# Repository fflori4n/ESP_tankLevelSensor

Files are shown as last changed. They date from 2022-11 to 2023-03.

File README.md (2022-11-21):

# ESP_tankLevelSensor

ESP32 measuring water level in a reservoar, using an external LM555 oscillator and a capacitive probe. 

Measurements are displayed on MAX7219 driven 7seg. displays and the uController hosts it's on webserver that displays the tank status and stats. Board has a linear regulator to drop the 12V DC from the truck's battery to 5V for the ESP and the sensor, two relays that can switch 12V DC external loads ( meant for signal lights ), and can drive WS2812B LED strip to indicate level in the tank.

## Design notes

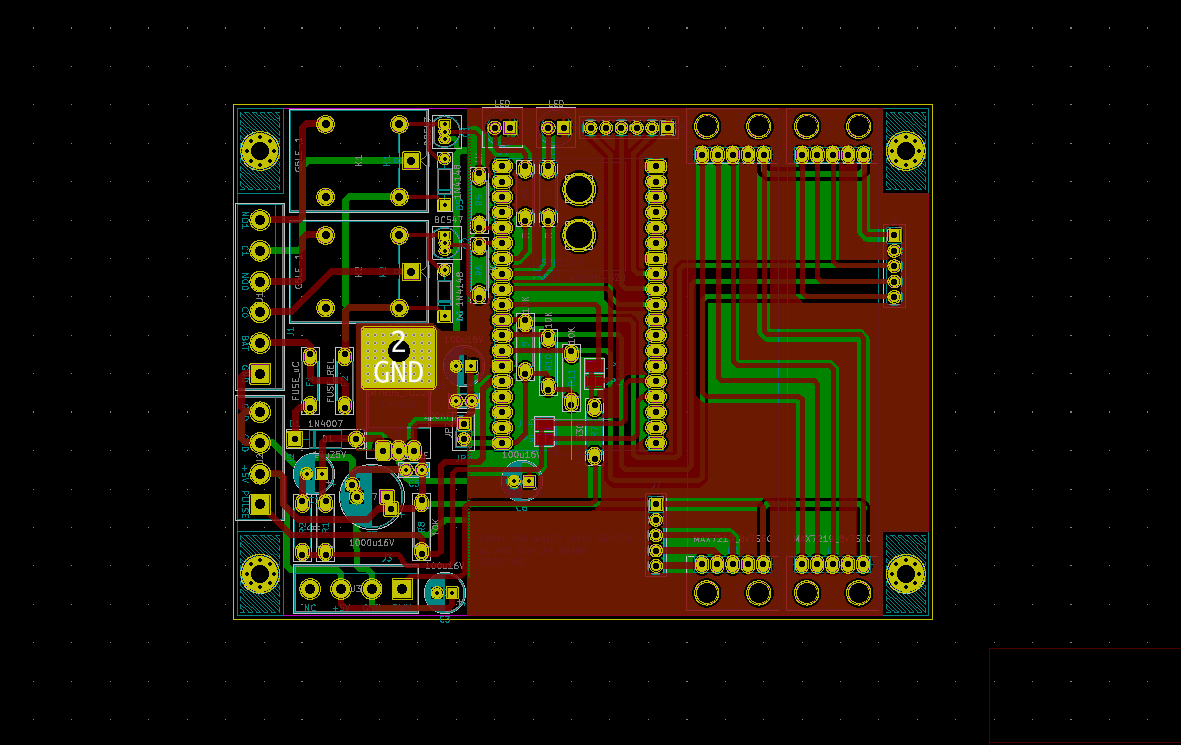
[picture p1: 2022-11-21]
doucmentation/Screenshot_pcb.png

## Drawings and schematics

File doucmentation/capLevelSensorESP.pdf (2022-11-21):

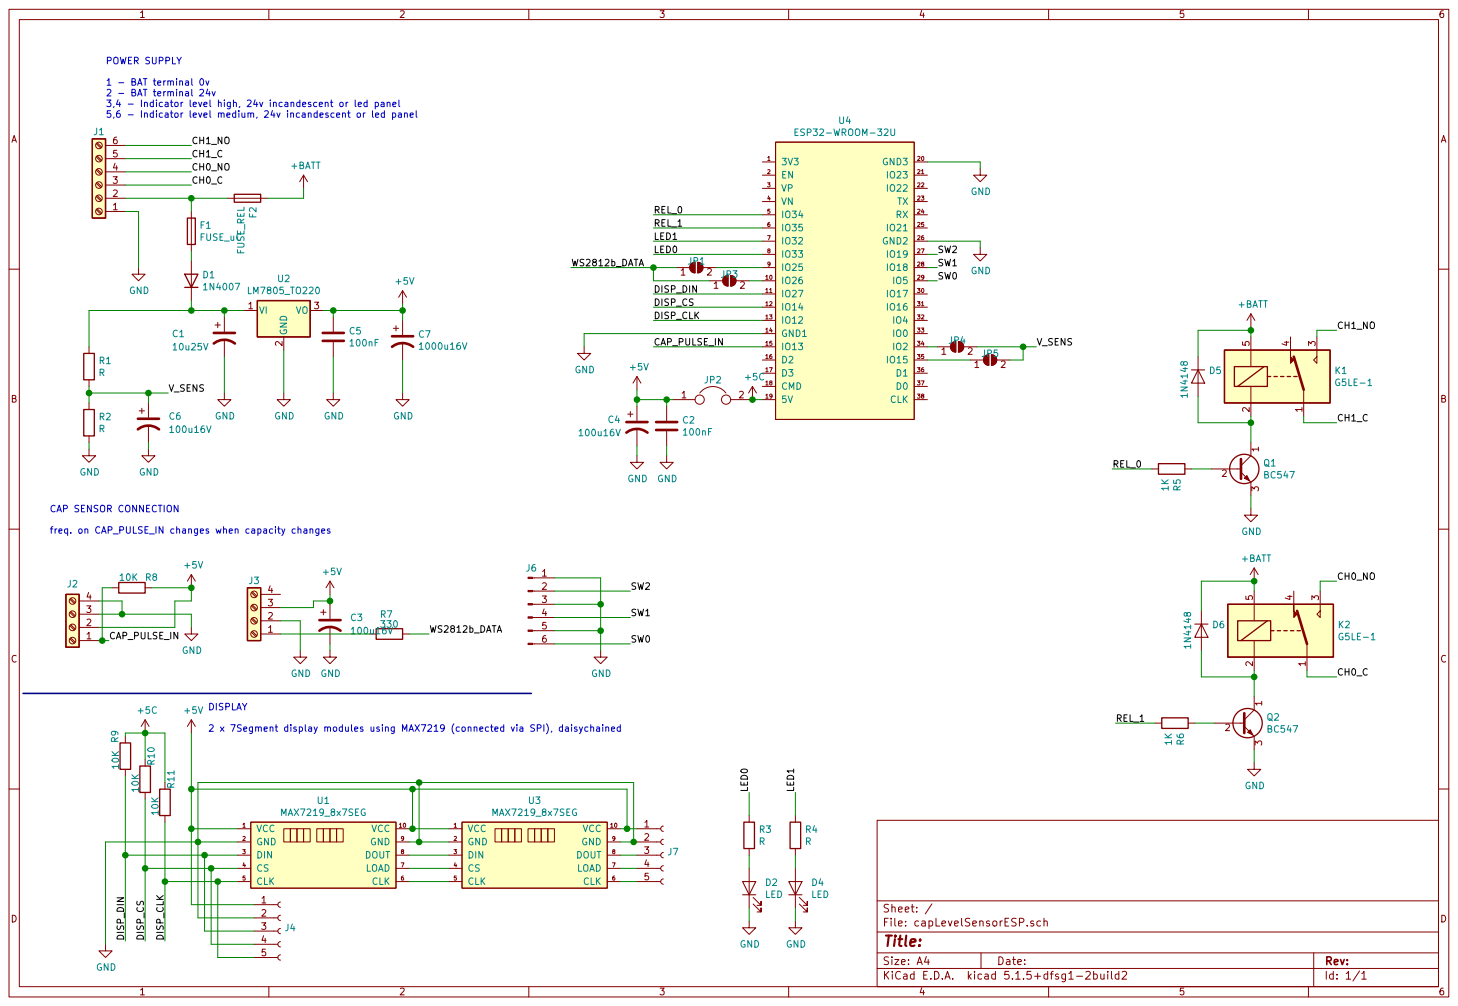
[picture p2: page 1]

1 - BAT terminal 0v 2 - BAT terminal 24v 3,4 - Indicator level high, 24v incandescent or led panel

File: capLevelSensorESP.sch Sheet: / F2 FUSE_REL

freq. on CAP_PULSE_IN changes when capacity changes DISPLAY

2 x 7Segment display modules using MAX7219 (connected via SPI), daisychained

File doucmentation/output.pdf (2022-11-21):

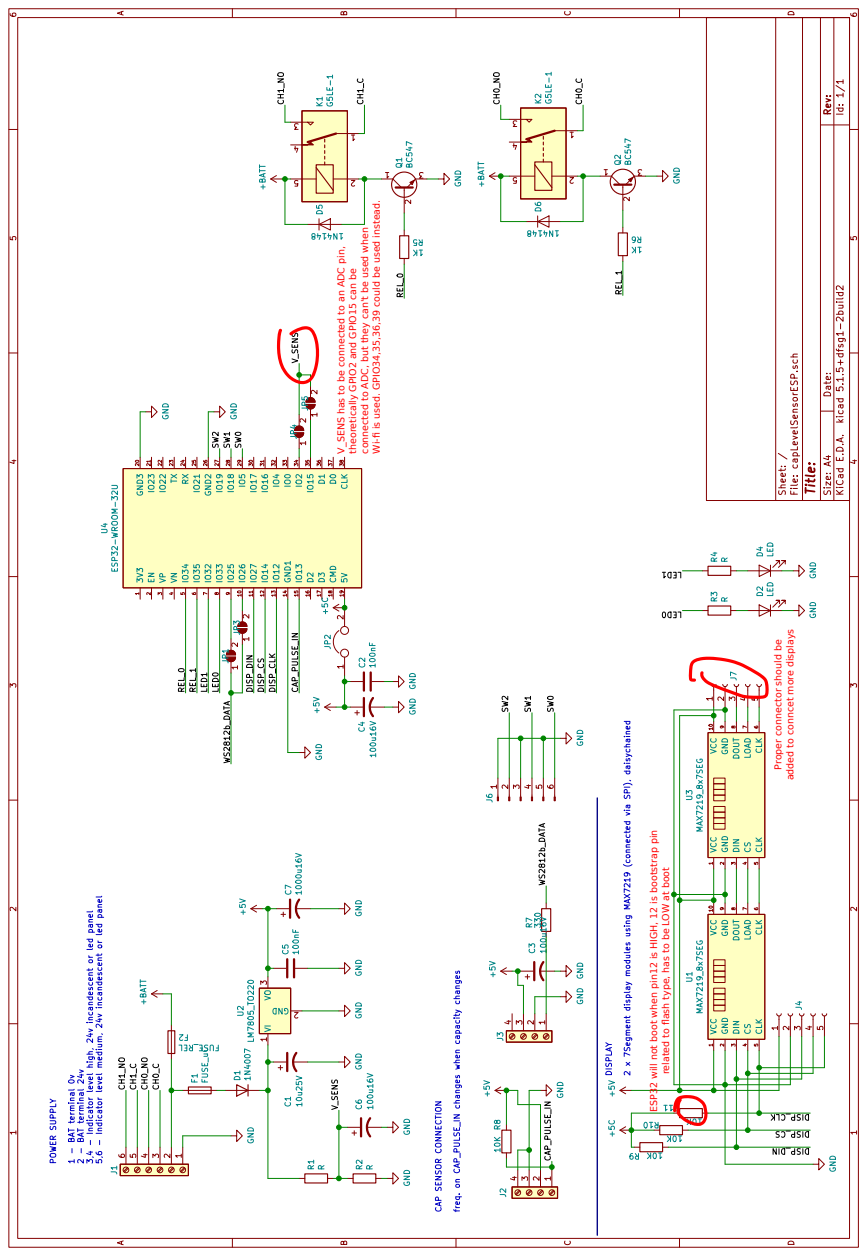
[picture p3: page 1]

Wi-fi is used. GPIO34,35,36,39 could be used instead.

connected to ADC, but they can't be used when

V_SENS has to be connected to an ADC pin,

theoretically GPIO2 and GPIO15 can be

added to conncet more displays

Proper connector should be

ESP32 will not boot when pin12 is HIGH, 12 is bootstrap pin

related to flash type, has to be LOW at boot

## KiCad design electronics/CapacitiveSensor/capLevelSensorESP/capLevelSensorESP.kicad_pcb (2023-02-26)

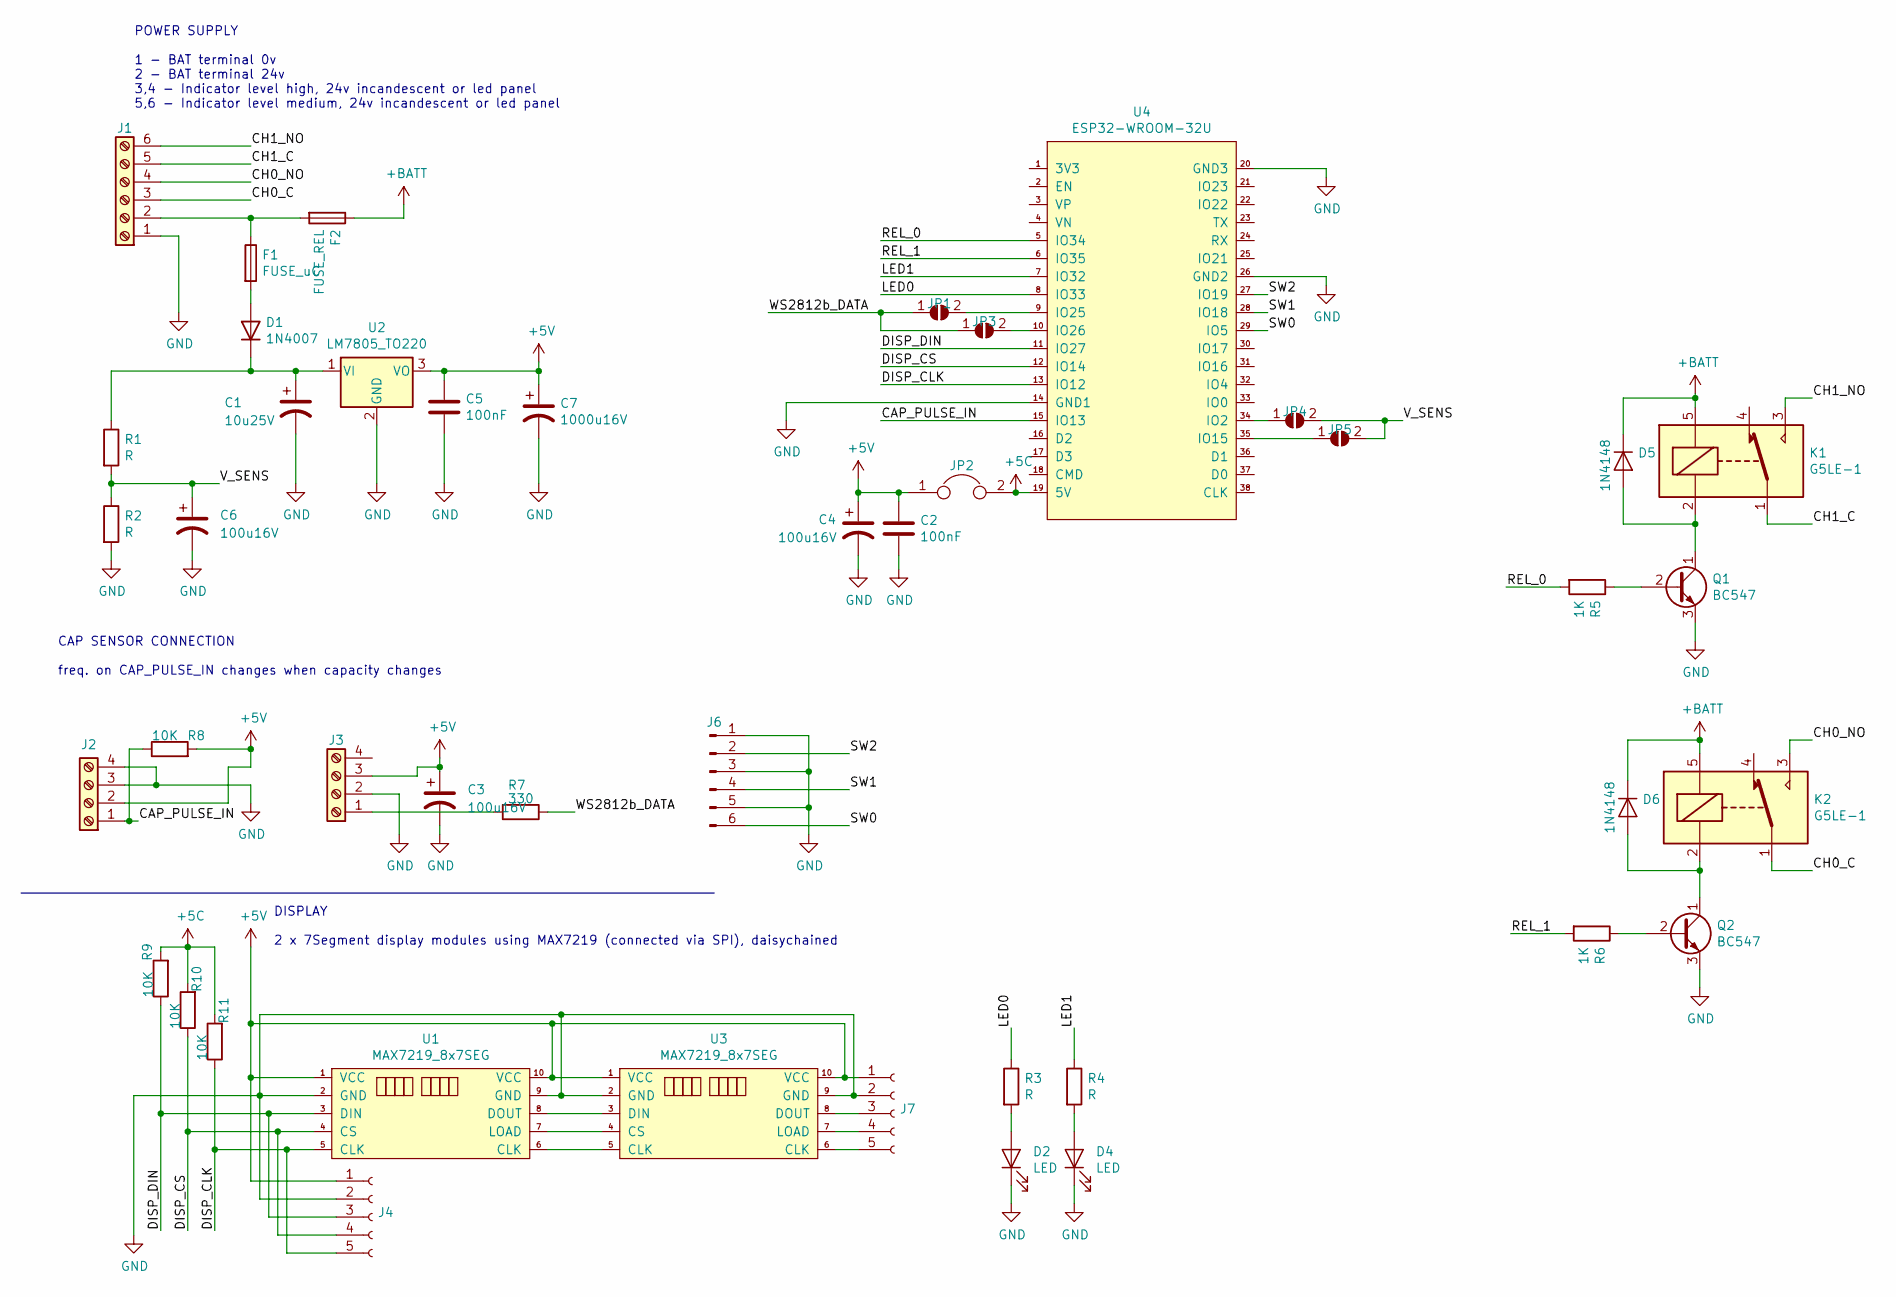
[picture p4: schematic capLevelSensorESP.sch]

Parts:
C1: 10u25V; CP_Radial_D6.3mm_P2.50mm
C2, C5: 100nF; Capker_L4.6mm_W2.0mm_P2.50mm
C3, C4, C6: 100u16V; CP_Radial_D6.3mm_P2.50mm
C7: 1000u16V; CP_Radial_D10.0mm_P5.00mm_P7.50mm
D1: 1N4007; D_DO-41_SOD81_P10.16mm_Horizontal
D2, D4: LED; LED_D5.0mm_FlatTop
D5, D6: 1N4148; D_DO-35_SOD27_P7.62mm_Horizontal
F1: FUSE_uC; resistor0.25,9mm
F2: FUSE_REL; resistor0.25,9mm
J1: TerminalBlock_bornier-6_P5.08mm
J2, J3: TerminalBlock_bornier-4_P5.08mm
J4, J7: PinHeader_1x05_P2.54mm_Vertical
J6: PinHeader_1x06_P2.54mm_Vertical
JP1, JP3, JP4, JP5: SolderJumper-2_P1.3mm_Open_Pad1.0x1.5mm
JP2: PinHeader_1x02_P2.54mm_Vertical
K1, K2: G5LE-1; Relay_SPDT_Omron-G5LE-1
Q1, Q2: BC547; TO-92_Inline
R1, R2, R3, R4: R; resistor0.25,9mm
R5, R6: 1K; resistor0.25,9mm
R7: 330; resistor0.25,9mm
R8, R9, R10, R11: 10K; resistor0.25,9mm
U1, U3: MAX7219_8x7SEG; 7SEG_DISPX8_MAX7219
U2: LM7805_TO220; TO-220-3_Horizontal_TabDown
U4: ESP32-WROOM-32U

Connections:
+5C: JP2.2, R9.2, R10.2, R11.2, U4.19 (5V); also elsewhere on the board
+5V: C2.1, C3.1, C4.1, C5.1, C7.1, J2.2, J3.3, J4.1, J7.1, JP2.1, R8.2, U1.1 (VCC), U1.10 (VCC), U2.3 (VO), U3.1 (VCC), U3.10 (VCC); also elsewhere on the board
+BATT: D5.1 (K), D6.1 (K), F2.1, K1.5, K2.5
/CAP_PULSE_IN: J2.1, R8.1, U4.15 (IO13); also elsewhere on the board
/CH0_C: J1.3, K2.1
/CH0_NO: J1.4, K2.3
/CH1_C: J1.5, K1.1
/CH1_NO: J1.6, K1.3
/DISP_CLK: J4.5, R11.1, U1.5 (CLK), U4.13 (IO12); also elsewhere on the board
/DISP_CS: J4.4, R10.1, U1.4 (CS), U4.12 (IO14); also elsewhere on the board
/DISP_DIN: J4.3, R9.1, U1.3 (DIN), U4.11 (IO27); also elsewhere on the board
/LED0: R3.1, U4.8 (IO33); also elsewhere on the board
/LED1: R4.1, U4.7 (IO32); also elsewhere on the board
/REL_0: R5.2, U4.5 (IO34); also elsewhere on the board
/REL_1: R6.2, U4.6 (IO35); also elsewhere on the board
/SW0: J6.6, U4.29 (IO5); also elsewhere on the board
/SW1: J6.4, U4.28 (IO18); also elsewhere on the board
/SW2: J6.2, U4.27 (IO19); also elsewhere on the board
/V_SENS: C6.1, JP4.2 (B), JP5.2 (B), R1.2, R2.1
/WS2812b_DATA: JP1.1 (A), JP3.1 (A), R7.1
GND: C1.2, C2.2, C3.2, C4.2, C5.2, C6.2, C7.2, D2.1 (K), D4.1 (K), J1.1, J2.3, J2.4, J3.2, J4.2, J6.1, J6.3, J6.5, J7.2, Q1.3 (E), Q2.3 (E), R2.2, U1.2 (GND), U1.9 (GND), U2.2 (GND), U3.2 (GND), U3.9 (GND), U4.14 (GND1), U4.20 (GND3), U4.26 (GND2); also elsewhere on the board
unnamed 21: C1.1, D1.2 (K), R1.1, U2.1 (VI); also elsewhere on the board
unnamed: D1.1 (A), F1.2
unnamed: D2.2 (A), R3.2
unnamed: D4.2 (A), R4.2
unnamed: D5.2 (A), K1.2, Q1.1 (C)
unnamed: D6.2 (A), K2.2, Q2.1 (C)
unnamed: F1.1, F2.2, J1.2
unnamed: J3.1, R7.2
unnamed: J7.3, U3.8 (DOUT)
unnamed: J7.4, U3.7 (LOAD)
unnamed: J7.5, U3.6 (CLK)
unnamed 33: JP1.2 (B), U4.9 (IO25); also elsewhere on the board
unnamed 34: JP3.2 (B), U4.10 (IO26); also elsewhere on the board
unnamed 35: JP4.1 (A), U4.34 (IO2); also elsewhere on the board
unnamed 36: JP5.1 (A), U4.35 (IO15); also elsewhere on the board
unnamed: Q1.2 (B), R5.1
unnamed: Q2.2 (B), R6.1
unnamed: U1.6 (CLK), U3.5 (CLK)
unnamed: U1.7 (LOAD), U3.4 (CS)
unnamed: U1.8 (DOUT), U3.3 (DIN)

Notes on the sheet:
POWER SUPPLY 1 - BAT terminal 0v 2 - BAT terminal 24v 3,4 - Indicator level high, 24v incandescent or led panel 5,6 - Indicator level medium, 24v incandescent or led panel
DISPLAY 2 x 7Segment display modules using MAX7219 (connected via SPI), daisychained
CAP SENSOR CONNECTION freq. on CAP_PULSE_IN changes when capacity changes

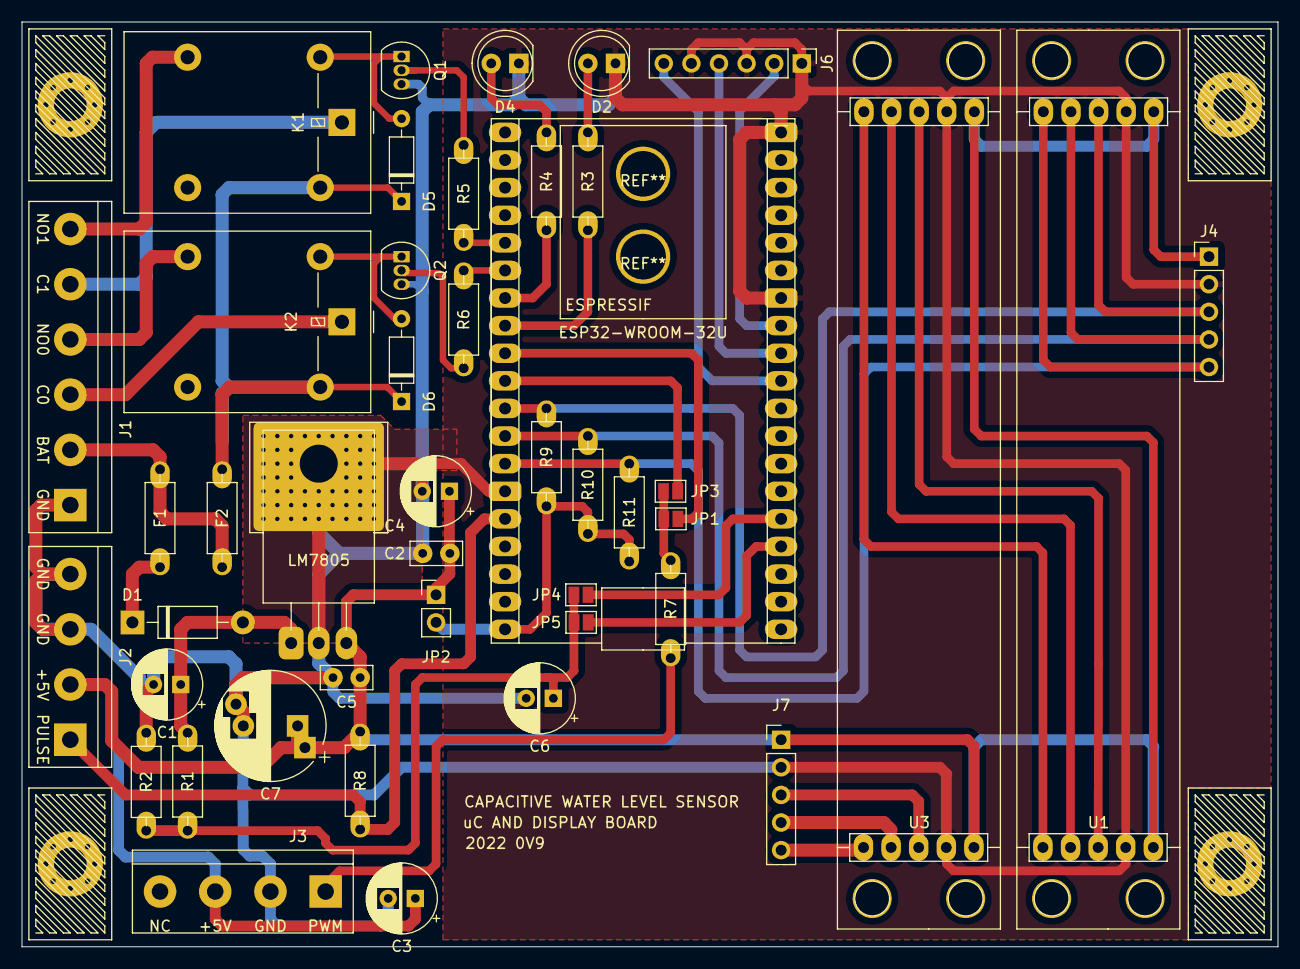
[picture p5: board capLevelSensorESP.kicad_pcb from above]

Board: 2 copper layers, 115.6 x 85.1 mm, 48 parts (0 on the bottom side), 41 nets.

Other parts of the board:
 : MountingHole_3mm_Pad_Via
 #2,  #3,  #4: MountingHole_3mm_Pad_Via
 #5: ESP32-WROOM-32U
LM7805: LM7805_TO220; TO-220-3_Horizontal_TabDown

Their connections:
+5C: #5.19; also elsewhere on the board
+5V: LM7805.3; also elsewhere on the board
/CAP_PULSE_IN: #5.15; also elsewhere on the board
/DISP_CLK: #5.13; also elsewhere on the board
/DISP_CS: #5.12; also elsewhere on the board
/DISP_DIN: #5.11; also elsewhere on the board
/LED0: #5.8; also elsewhere on the board
/LED1: #5.7; also elsewhere on the board
/REL_0: #5.5; also elsewhere on the board
/REL_1: #5.6; also elsewhere on the board
/SW0: #5.29; also elsewhere on the board
/SW1: #5.28; also elsewhere on the board
/SW2: #5.27; also elsewhere on the board
GND: #5.14, #5.20, #5.26, LM7805.2; also elsewhere on the board
unnamed 21: LM7805.1; also elsewhere on the board
unnamed 33: #5.9; also elsewhere on the board
unnamed 34: #5.10; also elsewhere on the board
unnamed 35: #5.34; also elsewhere on the board
unnamed 36: #5.35; also elsewhere on the board

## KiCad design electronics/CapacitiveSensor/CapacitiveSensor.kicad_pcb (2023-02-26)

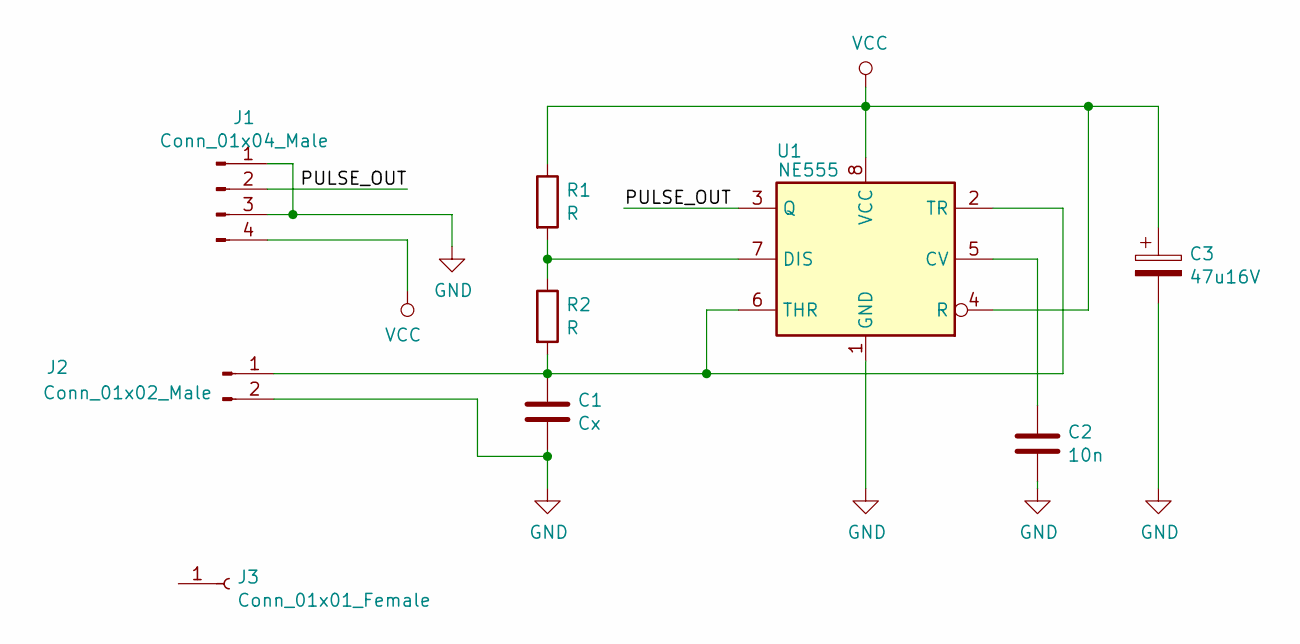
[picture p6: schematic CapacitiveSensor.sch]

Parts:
C1: Cx; Capker_L4.6mm_W2.0mm_P2.50mm
C2: 10n; Capker_L4.6mm_W2.0mm_P2.50mm
C3: 47u16V; CP_Radial_D7.5mm_P2.50mm
J1: Conn_01x04_Male; CopperPad_4x4_withZipTie
J2: Conn_01x02_Male; CopperPad_2x0.75
J3: Conn_01x01_Female; 4mmcableSteainRelief
R1, R2: R; resistor0.25,9mm
U1: NE555; DIP-8_W7.62mm_Large

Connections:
/PULSE_OUT: J1.2, U1.3 (Q)
GND: C1.2, C2.2, C3.2, J1.1, J1.3, J2.2, U1.1 (GND)
unnamed: C1.1, J2.1, R2.2, U1.2 (TR), U1.6 (THR)
unnamed: C2.1, U1.5 (CV)
unnamed: R1.2, R2.1, U1.7 (DIS)
VCC: C3.1, J1.4, R1.1, U1.4 (R), U1.8 (VCC)

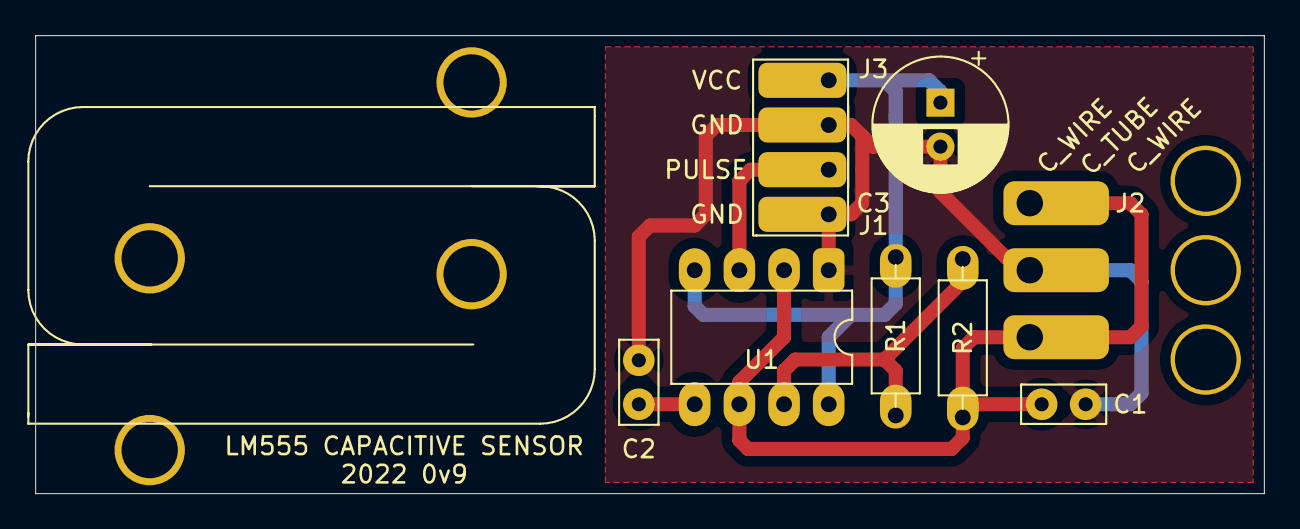
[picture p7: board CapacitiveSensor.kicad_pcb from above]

Board: 2 copper layers, 69.8 x 26.0 mm, 9 parts (0 on the bottom side), 6 nets.

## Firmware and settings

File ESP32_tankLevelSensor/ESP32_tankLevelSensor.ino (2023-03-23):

#define EEPROM_SIZE 100             /// EEPROM size, non volatile memory for storing averages and statistics when power is cut
#define _mainLoopDelay 50           /// delay for non precise timing, to limit Display and EEPROM writes
#define CAP_SENS_PIN 13             /// Capacitive sensor pin
#define LED_BLUE 32                 /// blue LED pin
#define LED_GREEN 33                /// green LED pin
#define CALIB_SWITCH_PIN 19         /// switch for going into calibration mode

#define ENCODER_A_PIN 18
#define ENCODER_B_PIN 5
#define ENCODER_BTN 17

#include <WiFi.h>
#include <ESPAsyncWebServer.h>
//#include <SPIFFS.h>
#include <EEPROM.h>

#include <DNSServer.h>          /// needed for captive AP
#include <AsyncTCP.h>


#include "index.h"              /// file containing html for web interface
#include "kFilt.h"
#include "lutFreqTransform.h"
#include "max7219.h"            /// containing methods for displaying stuff on 8x 7seg display
#include "eeprom.h"
#include "liquidLevel.h"        /// containing liquid level class for processing cap. sensor data

const char* hotspotSSID = "Water level sensor";   /// ESP hotspot name
const char* hotspotPasswd = "123456789";          /// ESP hotspot passwd


DNSServer dnsServer;                              /// create DNS server
AsyncWebServer server(80);                        /// create webserver on port 80 - AsyncWebServer

Display8x8 displays;

volatile double levelSensPulses = 0;          /// pulses measured from capacitive sensor
volatile double rawPulse = 0;
volatile double newReading = -1;

volatile int encoderInc = 0;
volatile int buttonPressed = 0;

int dispMenuNumber = 0;
bool editMode = false;
byte displayPages = 8;


/// TIMER ISR SETUP
hw_timer_t * timer = NULL;

LiquidLevel levelSens(2000, 0); /// new instance of liquid level class for capacitive sensor

class CaptiveRequestHandler : public AsyncWebHandler {  /// Captive access point class
  public:
    CaptiveRequestHandler() {}
    virtual ~CaptiveRequestHandler() {}

    bool canHandle(AsyncWebServerRequest *request) {
      //request->addInterestingHeader("ANY");
      return true;
    }

    void handleRequest(AsyncWebServerRequest *request) {
      request->send(200, "text/html", String(indexStr).c_str());
    }
};

void IRAM_ATTR isr() {        /// interrupt service routine, executerd on every sensor pin falling edge
  levelSensPulses++;          /// increase pulse count
}
void IRAM_ATTR timerISR() {   /// timer interrupt routine - executed every 100ms

  newReading = rawPulse = levelSensPulses;  /// TODO: ? this is probably not needed
  levelSens.setFreq((levelSensPulses * 10), 100); /// pass number of pulses in the last 100ms to function
  levelSensPulses = 0;
}
void encoderCallback() {
  static byte prevEncoder = 0;
  noInterrupts();

  byte encoder = ((digitalRead(ENCODER_B_PIN) && 0b00000001) << 1) | (digitalRead(ENCODER_A_PIN) && 0b00000001);

  // 1320 0231
  switch (encoder) {
    case 1:
      if (prevEncoder == 0) {
        //Serial.println("Encoder right");  /// should not be printing in ISR but didn't crash, so guess I can?
        encoderInc--;
      }
      else if (prevEncoder == 3) {
        //Serial.println("Encoder left");
        encoderInc++;
      }
      break;
  }
  prevEncoder = encoder;
  interrupts();
}
int readVpVoltage() {

#define VPPIN 36
#define VP_SCALE 12.26/1182  /// real voltage / ADC value

  static int vp = 1350;
  int vpRaw = (VP_SCALE * analogRead(VPPIN) * 100);
  vp = (vp * 0.95) + ( vpRaw * 0.05);
  /*Serial.print("VBAT| ");
    Serial.println(vp);
    Serial.print("ADC_BAT| ");
    Serial.println(analogRead(VPPIN));*/

  if(vp < minBatVoltage){
    minBatVoltage = vp;
  }
  return vp;
}
void wifiStop(){
   Serial.println("Disableing AP (Access Point)");
   WiFi.mode(WIFI_MODE_STA);
   WiFi.enableAP(false);
   WiFi.softAPdisconnect();
   WiFi.softAPdisconnect(false);
}
void wifiStart(){
  Serial.println("Setting AP (Access Point)");

  WiFi.mode(WIFI_AP);
  WiFi.softAP(hotspotSSID, hotspotPasswd);
  Serial.println("Wait 100 ms for AP_START...");
  delay(100);
  
  if(!WiFi.softAPConfig(IPAddress(192, 168, 4, 1), IPAddress(192, 168, 4, 1), IPAddress(255, 255, 255, 0))){
      Serial.println("AP Config Failed");
  }
  IPAddress myIP = WiFi.softAPIP();
  Serial.print("AP IP address: ");
  Serial.println(myIP);
  dnsServer.start(53, "*", WiFi.softAPIP());  /// Start DNS server
  
  server.on("/info", HTTP_GET, [](AsyncWebServerRequest * request) {          /// /info ==> levelSens.getInfoStr().c_str()
    request->send_P(200, "text/html", levelSens.getInfoStr().c_str());
  });
  server.on("/", HTTP_GET, [](AsyncWebServerRequest * request) {              /// / ==> String(indexStr).c_str() /// serve the index page stored in index.h
    request->send(200, "text/html", String(indexStr).c_str());
  });
  server.on("/generate_204", HTTP_GET, [](AsyncWebServerRequest * request) {  /// android connected to hotspot ==> String(indexStr).c_str() /// serve the index page stored in index.h
    request->send(200, "text/html", String(indexStr).c_str());
  });
  server.on("/fwlink", HTTP_GET, [](AsyncWebServerRequest * request) {        /// windows connected to hotspot ==> String(indexStr).c_str() /// serve the index page stored in index.h
    request->send(200, "text/html", String(indexStr).c_str());
  });
  server.onNotFound([](AsyncWebServerRequest * request) {                     /// request for some other webpage ==> String(indexStr).c_str() /// serve the index page stored in index.h
    request->send(200, "text/html", String(indexStr).c_str());
  });
  server.addHandler(new CaptiveRequestHandler()).setFilter(ON_AP_FILTER);     ///Redirect every request to captive portal
  server.begin();                                                             /// Start webserver
}
void setup() {

  pinMode(LED_BLUE, OUTPUT);      /// Set LED pins
  pinMode(LED_GREEN, OUTPUT);
  pinMode(CALIB_SWITCH_PIN, INPUT_PULLUP);      /// switch pin
  digitalWrite(LED_BLUE, HIGH);
  digitalWrite(LED_GREEN, HIGH);

  pinMode(13, INPUT_PULLUP);                                                  /// Capacitive Sensor pin -> pull up
  attachInterrupt(13, isr, FALLING);                                          /// Capacitive pin falling edge -> trigger interrupt

  pinMode(ENCODER_A_PIN, INPUT_PULLUP);
  pinMode(ENCODER_B_PIN, INPUT_PULLUP);
  pinMode(ENCODER_BTN, INPUT_PULLUP);
  attachInterrupt(ENCODER_A_PIN, encoderCallback, CHANGE); // Need to detect both rising or falling signal
  attachInterrupt(ENCODER_B_PIN, encoderCallback, CHANGE);
  attachInterrupt(ENCODER_BTN, encoderCallback, CHANGE);
  
  Serial.begin(115200);           /// start DBG serial
  EEPROM.begin(EEPROM_SIZE);      /// start EEprom
  levelSens.loadEEPROM();         /// load max water out, average flow from uController EEPROM

  timer = timerBegin(0, 80, true);                                            /// Initialise timer interrupt for every 100ms
  timerAttachInterrupt(timer, &timerISR, true);
  timerAlarmWrite(timer, 100000, true);
  timerAlarmEnable(timer);

  /// DISP INIT
  displays.init();
  displays.send2Disp(0x0f, 0x00, 0x00);  // Display mode: Test 0x01 : Normal 0x00
  displays.send2Disp(0x0c, 0x00, 0x00);   // Display : Shutdown 0x00 : On 0x01
  displays.send2Disp(0x0a, 0x01, 0x01);  // Brightness : 0x0
  displays.send2Disp(0x09, 0x00, 0x00);  // Decode mode: 0x00 - no decode, 0x01, 0x0F, 0xFF - ascii
  displays.send2Disp(0x0b, 0x07, 0x07);  // Scan Limit reg
  displays.send2Disp(0x0c, 0x01, 0x01);   // Display : Shutdown 0x00 : On 0x01
  /// DISP INIT

  if(wifiEnabled){
    wifiStart();
  }
}
bool confirmAction(){

  byte twists = 1;
  #define TIME_OUT_MS 2000
  for(int i=0; i< TIME_OUT_MS; i++){
    if(encoderInc > 0){
      twists+=encoderInc;}
    encoderInc = 0;
    displays.printConfirm(twists);
    delayMicroseconds(1000);
    if(twists > 8){
      delayMicroseconds(100000);
      encoderInc = 0;
      return true;
    }
  }
  return false;
}

int doNotUseMinimum = 0;
void loop() {

  delay(_mainLoopDelay);           /// delay
  levelSens.update();              /// update display values
  

  if( doNotUseMinimum >= (5000/_mainLoopDelay)){
    batVoltage = readVpVoltage();
  }
  else{
    doNotUseMinimum++;
  }
  
  displays.printMenu(dispMenuNumber, (levelSens.percent * 10), levelSens.flow, levelSens.ttEdgeSecs, -1, levelSens.filteredFreq, batVoltage, minBatVoltage, (int)(lut1Outputmms), (int)(lut2Outputmms),(int)levelSens.totalWaterUsed, (int)levelSens.measuredWaterUsed, (int)(levelSens.averageFallingFlow*100), (int)(levelSens.averageRisingFlow*100), wifiEnabled);
  
  if (digitalRead(CALIB_SWITCH_PIN)) {  /// switch for calibration
    digitalWrite(LED_GREEN, HIGH);
    levelSens.calibrate();
  }

  if (!digitalRead(ENCODER_BTN)) {      /// button press for navigation
    int buttonPressCounter = 0;
    while (!digitalRead(ENCODER_BTN) && buttonPressCounter < 1000) {
      buttonPressCounter += 1;
      delayMicroseconds(1000);
    }
    if (buttonPressCounter < 500) {
      buttonPressed += 1;
    }
    else {
      buttonPressed += 2;
    }
  }

  if(buttonPressed != 0){
    switch(dispMenuNumber){
      case 1: /// clear bat
        if(buttonPressed == 2 && confirmAction()){
            minBatVoltage = 9900;
            doNotUseMinimum = 0;
            levelSens.saveToEEPROM(true);
        }
        break;
      case 2: /// clear total
        if(buttonPressed == 2 && confirmAction()){
            levelSens.measuredWaterUsed = 0;
            levelSens.saveToEEPROM(true);
        }
        break;
       case 3: /// clear total
        if(displayPages == 11 && buttonPressed == 2 && confirmAction() && confirmAction()){
            levelSens.totalWaterUsed = 0;
            levelSens.saveToEEPROM(true);
        }
        break;
      case 5: /// clear total
        if(buttonPressed == 2 && confirmAction()){
            levelSens.averageFallingFlow = -10;
            levelSens.saveToEEPROM(true);
        }
        break;
      case 6: /// clear total
        if(buttonPressed == 2 && confirmAction()){
            levelSens.averageRisingFlow = 10;
            levelSens.saveToEEPROM(true);
        }
        break;
      case 7:
        if(buttonPressed == 2){
          if(confirmAction()){
            if(displayPages == 11){
              displayPages = 8;
            }
            else{
              displayPages = 11;
              Serial.println("debug mode enabled!");
            }
          }
        }
        break;
        case 8: /// clear total
        if(buttonPressed == 2 && confirmAction()){
          if(wifiEnabled != 0){
            wifiEnabled = 0;
            wifiStop();
          }
          else{
            wifiEnabled = 1;
            wifiStart();
          } 
          levelSens.saveToEEPROM(true);
        }
        break;
    }
    buttonPressed = 0;
  }
  if (!editMode) {
    if (encoderInc != 0) {
      if ( (dispMenuNumber + encoderInc) >= 0 && (dispMenuNumber + encoderInc) < displayPages) {
        dispMenuNumber += encoderInc;
        //Serial.print(dispMenuNumber);
      }
      encoderInc = 0;
    }
  }

  dnsServer.processNextRequest();   /// process DNS request if new phone is connected*/
}

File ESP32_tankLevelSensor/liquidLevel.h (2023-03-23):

double batVoltage = 0, minBatVoltage = 3000;
int wifiEnabled = 1;

class LiquidLevel{
  /// define memory locations in EEProm to contain total out and average flow variables
  /// flags for printing debug messeges 
  #define PRINT_RAWFREQ 1
  //#define PRINT_STATUS 1
  //#define PRINT_LOGDBG 1
  //#define PRINT_STATE

  #define SENS_BOTTOM_OFFSET 0
  #define SENS_TOP_OFFSET 0
  #define MAX_LITERS 2000
  #define SENS_MAX_LENGTHmm 1040
  
  private:
    String IpAddress2String(const IPAddress& ipAddress)
    {
      return String(ipAddress[0]) + String(".") +\
      String(ipAddress[1]) + String(".") +\
      String(ipAddress[2]) + String(".") +\
      String(ipAddress[3])  ; 
    }

    
    
  public:

    bool noConErr = false;        /// sensor not connected error

    double submergedPercent = -1;
    double litersInReservoir = -1;
    double prevLitersInReservoir = -1;
    double sensorSubmergedmm = 0;

    //double fullLiters;
    //double emptyLiters;
    //double fullFreq;
    //double emptyFreq;
    
    double rawFreq = -1;
    double filteredFreq = -1;
    double freqDt = -1;

    double dLiters = 0;
    double percent = -1;
    bool levelCalcRDY = false;

    double flowDt = 1;
    double flowNowFreq = 0;
    double flowNowLiters = 99999999;
    double flowPrevLiters = 99999999;
    bool flowCalcRDY = false;
    
    double flow = 0;
    double rawFlow = 0;
    double ttEdgeSecs = 0;
    //double ttEdgeSecsAvgOpen = 0;

    double avrgOutFlow=0;

    double totalWaterUsed = 0;
    double measuredWaterUsed = 0;
    double averageFallingFlow = -10;
    double averageRisingFlow = 10;
   

    unsigned int flowStatus = 0; /// 0 - STATIC, 1 - OUT, 2 - IN
    unsigned int levelStatus = 3; /// 0 - EMPTY, 1 - LOW, 2 - MID, 3 - HIGH, 4 - FULL

    float logIntervalCounter = 0;
    float tmCycle = 0;

    KalmanFilter levelLitersFilter;
    //KalmanFilter flowFilter;

    LiquidLevel(double fullLiters, double emptyLiters){
      //this->fullLiters = fullLiters;
      //this->emptyLiters = emptyLiters;

      levelLitersFilter.setRH(10,1);
      //flowFilter.setRH(5,1);
    }

    /**
     * @brief dt time has passed and freq number of pulses was counted, time to update sensor readings
     * 
     * @param freq 
     * @param dt 
     * 
     *  /// Keep this short, runs in ISR
     */
    void setFreq(double freq, double dt){
      #define AVGWEIGHT 0.95                                              /// weight of previous measurement in average filtering
      #define FLOW_MEASURE_INTERVAL 1000                                  /// log variables for flow calculation every  1000ms
      static double calcFlowDt = 0;

      
      this->rawFreq = freq;
      this->freqDt = dt; 

      if(this->filteredFreq == -1 && freq != -1){                        /// at initial measurement, use new value as average value
        this->filteredFreq = freq;
      }
      this->filteredFreq = ((filteredFreq * AVGWEIGHT) + (freq * (1 - AVGWEIGHT))); /// weighted average filtering of new value and average value
      levelCalcRDY = true;                                                /// set flag, new values have been recorded time to recalculate level

      
      calcFlowDt+= dt;                                                    /// increase time passed since last flow calc.
      if(calcFlowDt >= FLOW_MEASURE_INTERVAL){                            /// Check if enough time has passed, to rerecord measurements for flow calc.
        this->flowDt = calcFlowDt;
        this->flowNowFreq = this->filteredFreq;
        this->flowCalcRDY = true;
        calcFlowDt = 0;
      }
      logIntervalCounter += (dt*1.0)/1000;                                /// increase time passed since last EEPROM log

      //tmCycle += (dt*1.0)/1000;
    }

    void calibrate(){
      #define _SAMPLE_MS 500

      static int calibrationStep = 0;
      int msToStart = 5000;
      static int64_t tValveOpened, prevEspTime;
      
      Serial.print("calibrating sensor...");
      Serial.print("open valve in:");

      while(true){
        digitalWrite(LED_GREEN, HIGH);
        if(calibrationStep == 0){
          digitalWrite(LED_BLUE, HIGH);
        }
        delay(10);
        this-> update(false);

        switch(calibrationStep){
          case 0:
              Serial.print("0");
              Serial.print(",");
              Serial.println((int)this->rawFreq);
              calibrationStep++;
              tValveOpened = esp_timer_get_time();
            /*}*/
            break;
          case 1:
            int64_t now = esp_timer_get_time();
            if((now - prevEspTime) >= (1000 * _SAMPLE_MS)){  /// every 100 ms
              prevEspTime = now;
              Serial.print((now - tValveOpened)/1000);
              Serial.print(",");
              Serial.println((int)this->rawFreq);
            }
            if(digitalRead(CALIB_SWITCH_PIN) == 0){
              digitalWrite(LED_GREEN, LOW);
              Serial.println("calibration mode exit.");
              delay(10000);
              return;
            }
            break;
        }
      }
    }
   
  
    /**
    * @brief Write 'total water out' and 'average flow' to non volatile EEPROM, these values remain even after microcontroller power off
    * Log interval changes depending on flow values, if flow is small, log period long, - if flow big, log period small
    */

    #define EEPROM_TOTAL_WATER_USED_H 0
    #define EEPROM_TOTAL_WATER_USED_L 1
    #define EEPROM_MEASURED_WATER_USED_H 2
    #define EEPROM_MEASURED_WATER_USED_L 3
    #define EEPROM_FALLING_FLOW_H 4
    #define EEPROM_FALLING_FLOW_L 5
    #define EEPROM_RISING_FLOW_H 6
    #define EEPROM_RISING_FLOW_L 7
    #define EEPROM_MINBATV_H 8
    #define EEPROM_MINBATV_L 9
    #define EEPROM_WIFIEN_H 10
    #define EEPROM_WIFIEN_L 11
    
    void saveToEEPROM(bool force = false){
      #define SHORT_LOG_PERIOD 15
      #define LONG_LOG_PERIOD (15*60)
      #define _maxLogRate (60/15)
      #define _minLogRate 60
      //#define _periodicLog false
     // #define PRINT_LOGDBG

      static unsigned int minLogInterval = SHORT_LOG_PERIOD;
      unsigned int logLimit = constrain(map(abs(flow),50,0,SHORT_LOG_PERIOD,LONG_LOG_PERIOD),SHORT_LOG_PERIOD,LONG_LOG_PERIOD);
      minLogInterval = min(minLogInterval, logLimit);
      
      #ifdef PRINT_LOGDBG
      Serial.print(logLimit);
      Serial.print(" ");
      
      
      Serial.print(logIntervalCounter);
      Serial.print(" > ");
      Serial.println(minLogInterval);
      #endif
      
      if(force || (logIntervalCounter > minLogInterval)){
        logIntervalCounter = 0;
        minLogInterval = _minLogRate * 60;
       // Serial.println("LOG LOG");
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

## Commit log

2023-02-18 added calibration function
2023-02-19 probe calibrated, but TODO: optimise LUT process and add features to change calibration
2023-02-26 added kicad files for PCBs
    [CapacitiveSensor-B_Cu.gbr, CapacitiveSensor-B_Mask.gbr, CapacitiveSensor-B_Paste.gbr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]
2023-03-09 worked on web interface with my new best collegue, chatGPT. And updated values for 1040mm sensor instead of 1000mm
2023-03-09 worked on encoder and button actions, cleaned up main, added webpages (chatgpt does not know how water looks like XD, but whatever saved it for future reference it still helped me a lot)
2023-03-11 reworked the EEProm reading and writing
    [ESP32_tankLevelSensor.ino, liquidLevel.h]
2023-03-15 fixed remaining time displayed format
    [ESP32_tankLevelSensor.ino, liquidLevel.h]
2023-03-23 added minimum battery level, new probe will be calibrated again @TODO: add calc sheet to git
